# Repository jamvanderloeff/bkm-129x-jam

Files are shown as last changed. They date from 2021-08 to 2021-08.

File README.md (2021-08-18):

A full sized version of the BKM-129X compatible board, modified by jam

Rev. 1.0

BKM-129X-MCU code from https://github.com/skumlos/bkm-129x-mcu

Output ports are all actively buffered, so no need for terminators.

Connections from top to bottom when viewing component side, with BNCs to the left:
               _______________________________________
            __| _                                     |
Y/G IN     |___|_|                                    |
            __| _                                     |
Y/G OUT    |___|_|                                   _|
            __| _                                   | |
B-Y/B IN   |___|_|                                  | |
            __| _                                   | |
B-Y/B OUT  |___|_|                                  | |
            __| _                                   | |
R-Y/R IN   |___|_|                                  | |
            __| _                                   | |
R-Y/R OUT  |___|_|                                  | |
            __| _                                   |_|
SYNC IN    |___|_|                                    |
            __| _                                     |
SYNC OUT   |___|_|                                    |
              |_______________________________________|

Just like the original BKM-129X.

For more information go to https://immerhax.com/?p=422

You are welcome to clone, produce and sell hardware based on this. Please keep changes and so on open source.

Cool kids give credit where due.

Should be compatible with basically all monitors that accept the original BKM-129X

Check the MCU code for verified compatibility.

---------

Board revision history:

Jam's fork 1.0 

C: Fixed THS7374 filter bypass.

B: Added onboard MCU option

A: Initial version

---------

Copyright © 2020 Martin Hejnfelt <martin@hejnfelt.com> and 2021 James van der Loeff <jam@wakabavideo.com>
This work is free. You can redistribute it and/or modify it under the
terms of the Do What The Fuck You Want To Public License, Version 2,
as published by Sam Hocevar. See the LICENSE file for more details.

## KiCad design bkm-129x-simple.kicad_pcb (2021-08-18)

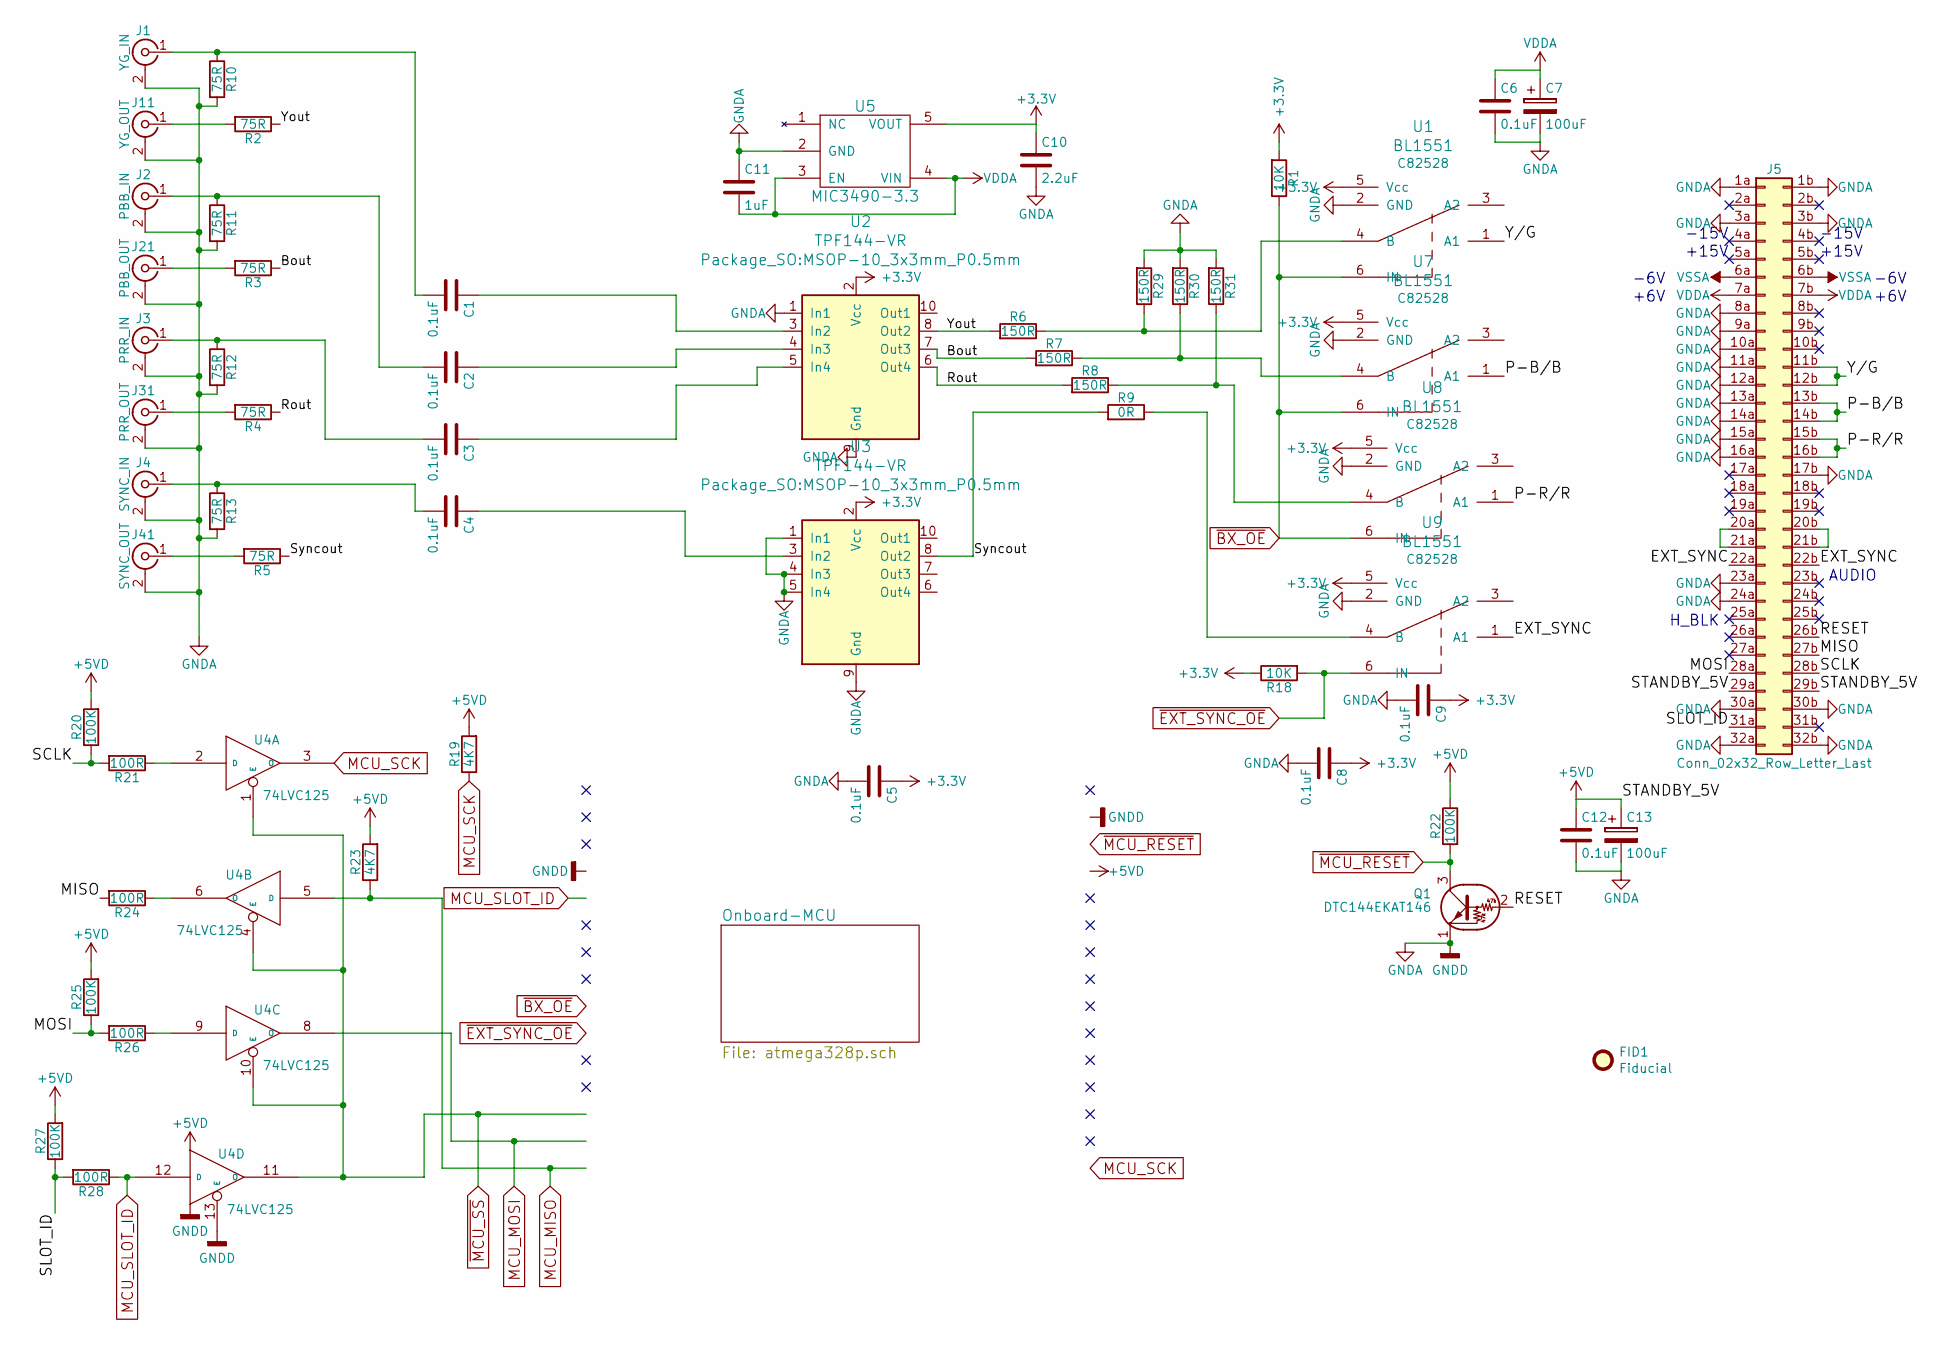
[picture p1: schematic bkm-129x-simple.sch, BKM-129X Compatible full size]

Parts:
C1, C2, C3, C4, C5, C6, C8, C9, C12: 0.1uF; C_0805_2012Metric_Pad1.18x1.45mm_HandSolder; LCSC C49678
C7, C13: 100uF; CP_Elec_6.3x5.3; LCSC C72477
C10: 2.2uF; C_0805_2012Metric_Pad1.18x1.45mm_HandSolder; LCSC C49217
C11: 1uF; C_0805_2012Metric_Pad1.18x1.45mm_HandSolder; LCSC C28323
FID1: Fiducial; borgar
J1: YG_IN; BNC-THT; LCSC NOT FITTED
J2: PBB_IN; BNC-THT; LCSC NOT FITTED
J3: PRR_IN; BNC-THT; LCSC NOT FITTED
J4: SYNC_IN; BNC-THT; LCSC NOT FITTED
J5: Conn_02x32_Row_Letter_Last; DIN-41612-64P; LCSC NOT FITTED
J11: YG_OUT; BNC-THT; LCSC NOT FITTED
J21: PBB_OUT; BNC-THT; LCSC NOT FITTED
J31: PRR_OUT; BNC-THT; LCSC NOT FITTED
J41: SYNC_OUT; BNC-THT; LCSC NOT FITTED
Q1: DTC144EKAT146; SOT-23; LCSC C111729
R1, R18: 10K; R_0805_2012Metric_Pad1.20x1.40mm_HandSolder
R2, R3, R4, R5, R10, R11, R12, R13: 75R; R_0805_2012Metric_Pad1.20x1.40mm_HandSolder
R6, R7, R8, R29, R30, R31: 150R; R_0805_2012Metric_Pad1.20x1.40mm_HandSolder
R9: 0R; R_0805_2012Metric_Pad1.20x1.40mm_HandSolder
R19, R23: 4K7; R_0805_2012Metric_Pad1.20x1.40mm_HandSolder
R20, R22, R25, R27: 100K; R_0805_2012Metric_Pad1.20x1.40mm_HandSolder
R21, R24, R26, R28: 100R; R_0805_2012Metric_Pad1.20x1.40mm_HandSolder
U1, U7, U8, U9: BL1551; SOT-363_SC-70-6; LCSC C82528
U2, U3: TPF144-VR; MSOP-10_3x3mm_P0.5mm; LCSC C155447
U4: 74LVC125; TSSOP-14_4.4x5mm_Pitch0.65mm; LCSC C6059
U5: MIC3490-3.3; SOT-23-5_HandSoldering

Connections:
+3V3: C5.1, C8.1, C9.1, C10.1, R1.2, R18.1, U1.5 (Vcc), U2.2 (Vcc), U3.2 (Vcc), U5.5 (VOUT), U7.5 (Vcc), U8.5 (Vcc), U9.5 (Vcc)
+5VD: C12.1, C13.1, J5.29a, J5.29b, R19.2, R20.2, R22.1, R23.2, R25.2, R27.2, U4.14 (VCC); also elsewhere on the board
/Bout: R3.1, R7.2, U2.7 (Out3)
/EXT_SYNC: J5.22a, J5.22b, U9.1 (A1)
/MISO: J5.27b, R24.2
/MOSI: J5.28a, R25.1, R26.2
/P-B/B: J5.13b, J5.14b, U7.1 (A1)
/P-R/R: J5.15b, J5.16b, U8.1 (A1)
/RESET: J5.26b, Q1.2 (B)
/Rout: R4.1, R8.2, U2.6 (Out4)
/SCLK: J5.28b, R20.1, R21.2
/SLOT_ID: J5.31a, R27.1, R28.2
/Syncout: R5.1, R9.2, U3.8 (Out2)
/Y/G: J5.11b, J5.12b, U1.1 (A1)
/Yout: R2.1, R6.2, U2.8 (Out2)
GND: C5.2, C6.2, C7.2, C8.2, C9.2, C10.2, C11.1, C12.2, C13.2, J1.2 (Ext), J2.2 (Ext), J3.2 (Ext), J4.2 (Ext), J5.1a, J5.1b, J5.3a, J5.3b, J5.8a, J5.9a, J5.10a, J5.11a, J5.12a, J5.13a, J5.14a, J5.15a, J5.16a, J5.17b, J5.23a, J5.24a, J5.30a, J5.30b, J5.32a, J5.32b, J11.2 (Ext), J21.2 (Ext), J31.2 (Ext), J41.2 (Ext), Q1.1 (E), R10.2, R11.2, R12.2, R13.2, R29.2, R30.2, R31.2, U1.2 (GND), U2.1 (In1), U2.9 (Gnd), U3.1 (In1), U3.4 (In3), U3.5 (In4), U3.9 (Gnd), U4.7 (GND), U4.13 (E), U5.2 (GND), U7.2 (GND), U8.2 (GND), U9.2 (GND); also elsewhere on the board
MCU_MISO: R23.1, U4.5 (D); also elsewhere on the board
MCU_MOSI: U4.8 (O); also elsewhere on the board
MCU_SCK: R19.1, U4.3 (O); also elsewhere on the board
MCU_SLOT_ID: R28.1, U4.12 (D); also elsewhere on the board
unnamed: C1.1, U2.3 (In2)
unnamed: C1.2, J1.1 (In), R10.1
unnamed: C2.1, U2.4 (In3)
unnamed: C2.2, J2.1 (In), R11.1
unnamed: C3.1, U2.5 (In4)
unnamed: C3.2, J3.1 (In), R12.1
unnamed: C4.1, U3.3 (In2)
unnamed: C4.2, J4.1 (In), R13.1
unnamed: J5.20a, J5.21a
unnamed: J5.20b, J5.21b
unnamed: J11.1 (In), R2.2
unnamed: J21.1 (In), R3.2
unnamed: J31.1 (In), R4.2
unnamed: J41.1 (In), R5.2
unnamed: R9.1, U9.4 (B)
unnamed: R21.1, U4.2 (D)
unnamed: R24.1, U4.6 (O)
unnamed: R26.1, U4.9 (D)
unnamed: R6.1, R29.1, U1.4 (B)
unnamed: R7.1, R30.1, U7.4 (B)
unnamed: R8.1, R31.1, U8.4 (B)
VDDA: C6.1, C7.1, C11.2, J5.7a, J5.7b, U5.3 (EN), U5.4 (VIN)
VSSA: J5.6a, J5.6b
~BX_OE: R1.1, U1.6 (IN), U7.6 (IN), U8.6 (IN); also elsewhere on the board
~EXT_SYNC_OE: R18.2, U9.6 (IN); also elsewhere on the board
~MCU_RESET: Q1.3 (C), R22.2; also elsewhere on the board
~MCU_SS: U4.1 (E), U4.4 (E), U4.10 (E), U4.11 (O); also elsewhere on the board

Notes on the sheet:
-15V
+15V
-6V
+6V
AUDIO
H_BLK

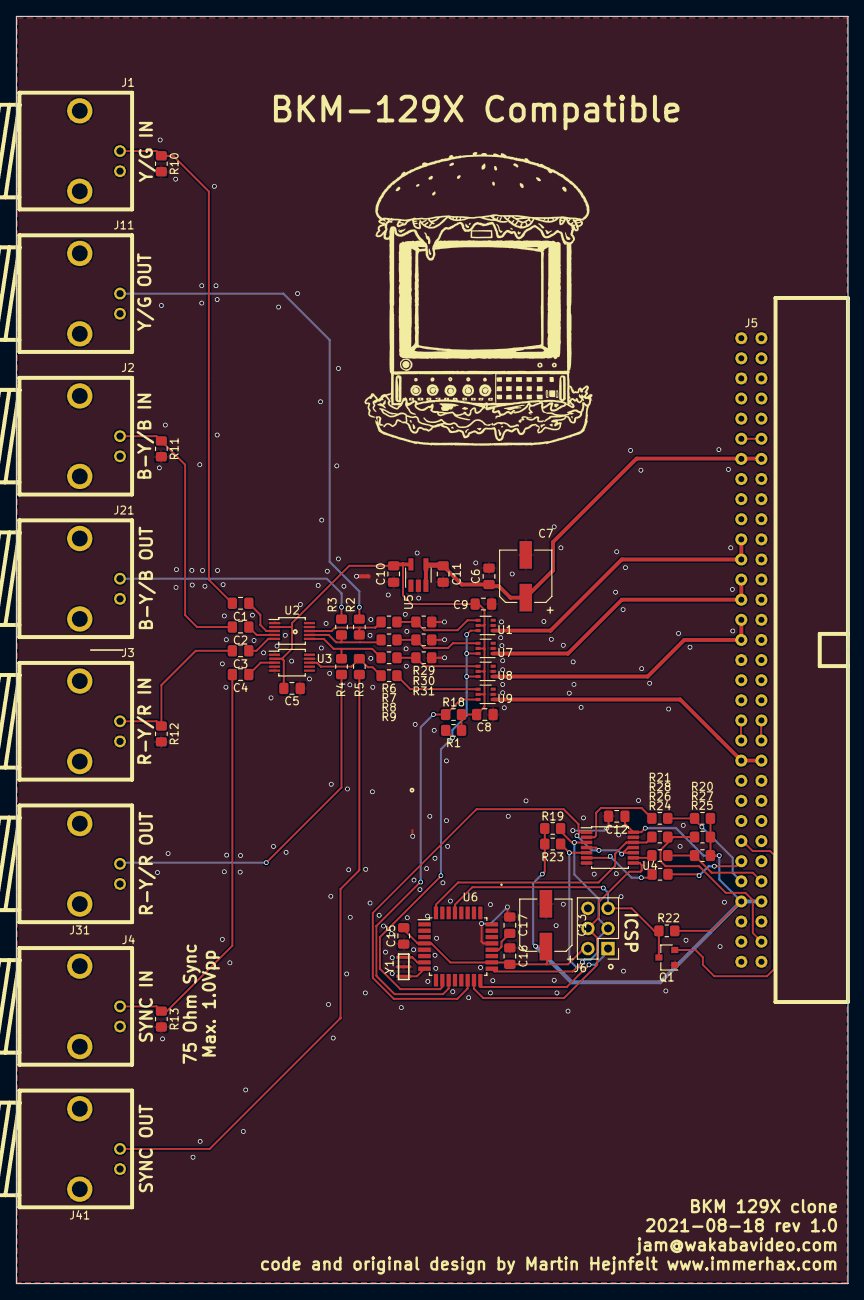
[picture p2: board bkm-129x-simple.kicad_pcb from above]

Board: 2 copper layers, 105.0 x 160.0 mm, 65 parts (0 on the bottom side), 50 nets.

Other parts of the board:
C15: 1uF; C_0805_2012Metric_Pad1.18x1.45mm_HandSolder
C16: 4.7uF; C_0805_2012Metric_Pad1.18x1.45mm_HandSolder
C17: 0.1uF; C_0805_2012Metric_Pad1.18x1.45mm_HandSolder
J6: ICSP; Pin_Header_Straight_2x03_Pitch2.54mm
U6: ATMEGA328PB-AU; TQFP-32_7x7mm_Pitch0.8mm
Y1: CSTNE16M0VH3L000R0; CSTNEx

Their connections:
+5VD: C15.1, C16.1, J6.2, U6.4, U6.18; also elsewhere on the board
GND: C15.2, C16.2, C17.1, J6.6, U6.5, U6.21, Y1.2; also elsewhere on the board
MCU_MISO: J6.1, U6.16; also elsewhere on the board
MCU_MOSI: J6.4, U6.15; also elsewhere on the board
MCU_SCK: J6.3, U6.17; also elsewhere on the board
MCU_SLOT_ID: U6.32; also elsewhere on the board
unnamed: C17.2, U6.20
unnamed: U6.7, Y1.1
unnamed: U6.8, Y1.3
~BX_OE: U6.10; also elsewhere on the board
~EXT_SYNC_OE: U6.11; also elsewhere on the board
~MCU_RESET: J6.5, U6.29; also elsewhere on the board
~MCU_SS: U6.14; also elsewhere on the board
